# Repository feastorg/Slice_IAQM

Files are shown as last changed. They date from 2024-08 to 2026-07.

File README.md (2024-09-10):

# Industrial Air Quality Monitor

Industrial air quality monitor and alarm for BREAD.

## Introduction

[Short introduction on the project.]

## Usage

[Explain how to use the project. Include examples and screenshots if applicable.]

## Documentation

Please refer to the [docs](/docs) for more info.

---

<div align="center">
  <p>
    
    
  </p>
</div>

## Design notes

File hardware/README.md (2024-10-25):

## IAQM - Industrial Air Quality Monitor 

## Requirements

### Requirements List

- **Data Logging**
  - Logging of data to SD card
  - Real-time clock for accurate data logging

- **Feedback Alarms**
  - Visual feedback alarm
  - Auditory feedback alarm

- **Air Quality Readings**
  - Ambient temperature sensor
  - Ambient humidity sensor
  - Barometric pressure sensor
  - CO gas sensor
  - CH₄ gas sensor
  - NH₃ gas sensor
  - H₂S gas sensor
  - H₂ gas sensor
  - Smoke / flammable gas sensor
  - VOCs (Volatile Organic Compounds)
    - eCO2 readings
  - AQI (Air Quality Index)

### Component Table

| **Name** | **Parameters Measured** | **Value Abbreviation** | **Notes** |
|---|---|---|---|
| SD Card Reader | Data Logging | N/A | |
| Real Time Clock | Global Local Time | N/A | |
| Piezo Buzzer | Auditory Feedback | N/A | For Alarm |
| Large LED | Visual Feedback | N/A | For Alarm |
| MQ-7 | Carbon Monoxide | CO | 10～500ppm, needs cycled coil heating. |
| MQ-137 | Ammonia Gas | NH₃ | 5～500ppm |
| MQ-8 | Hydrogen Gas | H₂ | 100～1000ppm |
| MQ-136 | Hydrogen Sulfide Gas | H₂S | 1～200ppm |
| MQ-2 | Smoke / Combustible Gas | N/A | 300～10000ppm (flammable gas) |
| MQ-3 | Alcohol Gas | C₂H₅OH | 25 ~ 500ppm (alcohol). Detects alcohol gases like a breathalyzer, not added in default build. |
| MQ-4 | Methane CNG Gas | CH₄ | 300～10000ppm |
| MQ-6 | Liquefied Petroleum Gas (LPG) | C₃H₈ | 300～10000ppm (propane). Not in default build. |
| BME 280 | Ambient Temperature, Relative Humidity, Barometric Pressure | N/A | Ambient Temp. -40 - +85 °C, Rel. Humidity 0 - 100 %, Baro. Pressure 300 - 1100 hPa |
| ENS160 | Total Volatile Organic Compounds, Equivalent Carbon Dioxide, Air Quality Index | TVOC, eCO₂, AQI | TVOC 0 – 65,000 ppb, eCO2 400 – 65,000ppm (CO₂ equiv.), AQI-UBA 1 to 5 |

### PV Box

| **Name** | **Parameters Measured** | **Value Abbreviation** | **Notes** |
|---|---|---|---|
| SD Card Reader | Data Logging | N/A | |
| Real Time Clock | Global Local Time | N/A | |
| Piezo Buzzer | Auditory Feedback | N/A | For Alarm |
| Large LED | Visual Feedback | N/A | For Alarm |
| MQ-7 | Carbon Monoxide | CO | 10～500ppm, needs cycled coil heating. |
| MQ-137 | Ammonia Gas | NH₃ | 5～500ppm |
| MQ-8 | Hydrogen Gas | H₂ | 100～1000ppm |
| MQ-136 | Hydrogen Sulfide Gas | H₂S | 1～200ppm |
| MQ-4 | Methane CNG Gas | CH₄ | 300～10000ppm |
| MQ-9B | Carbon Monoxide & Methane CNG Gas | CO & CH₄ | 10～500ppm CO, 300～10000ppm CH4 |
| BME 280 | Ambient Temperature, Relative Humidity, Barometric Pressure | N/A | Ambient Temp. -40 - +85 °C, Rel. Humidity 0 - 100 %, Baro. Pressure 300 - 1100 hPa |
| ENS160 | Total Volatile Organic Compounds, Equivalent Carbon Dioxide, Air Quality Index | TVOC, eCO₂, AQI | TVOC 0 – 65,000 ppb, eCO2 400 – 65,000ppm (CO₂ equiv.), AQI-UBA 1 to 5 |

### Parts List

- SD conn: https://www.mouser.ca/ProductDetail/Molex/502570-0893?qs=xbccQsLEe0eiL%252BVgS3E4nA%3D%3D
- SD level shifter: https://www.mouser.ca/ProductDetail/Texas-Instruments/TXB0104D?qs=oFXvjAmG9Eh0u9dpGkn5zg%3D%3D
- batt holder: https://www.mouser.ca/ProductDetail/Keystone-Electronics/3000?qs=Mn60vILZNNbcLh3ZnzbtUw%3D%3D

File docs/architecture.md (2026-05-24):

---
title: "Architecture"
description: "Hardware and firmware architecture overview."
---

# Architecture

## Hardware

Indoor Air Quality Monitor (IAQM) slice. Integrates BME280 (temp/humidity/pressure), ENS160 (VOC/eCO2), MQ gas sensor, RTC, and microSD card logging with 1.8V regulator.

## Firmware

_Not yet developed._

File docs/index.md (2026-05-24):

---
title: "Slice IAQM Documentation"
description: "Overview and entry page for Slice IAQM project documentation."
nav_exclude: true
---

Welcome to the Slice IAQM project documentation.

## Board Renders

<figure style="display:inline-block; text-align:center; margin:10px;">
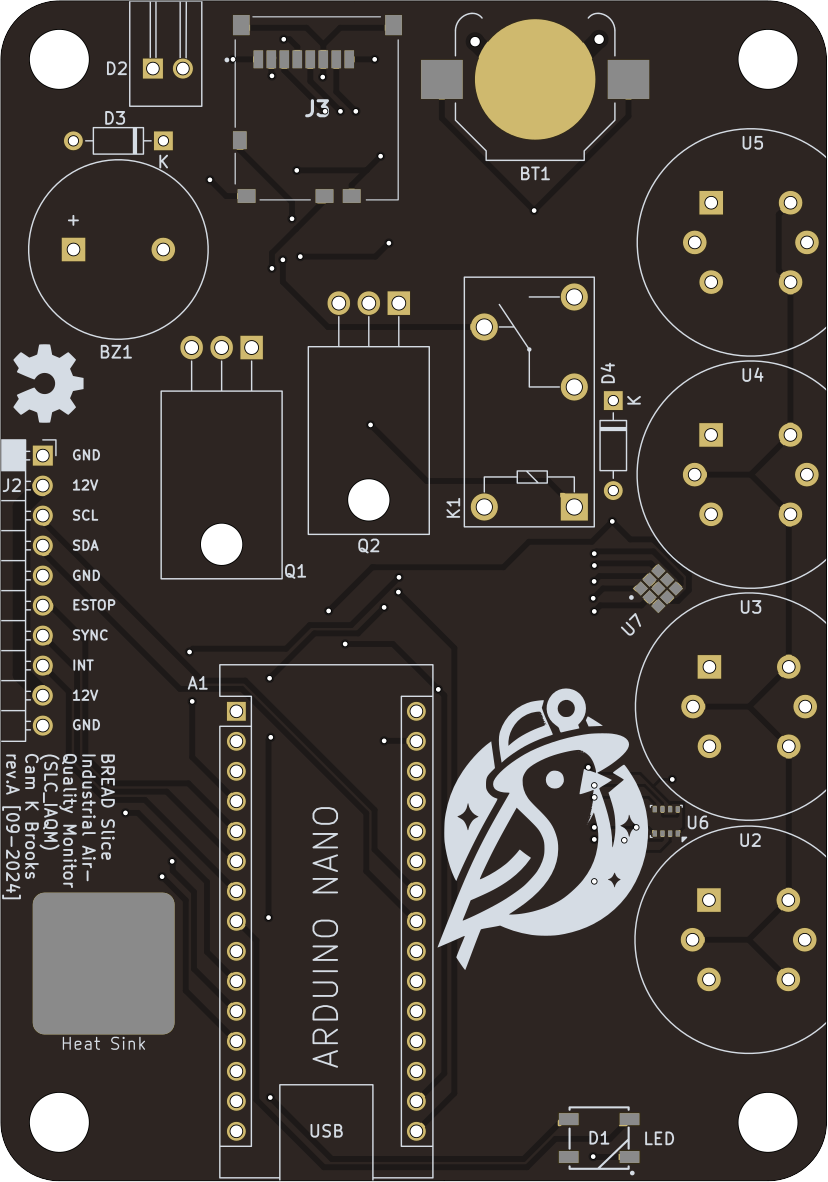
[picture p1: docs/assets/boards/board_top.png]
Board Top
  
  <figcaption>Top</figcaption>
</figure>

<figure style="display:inline-block; text-align:center; margin:10px;">
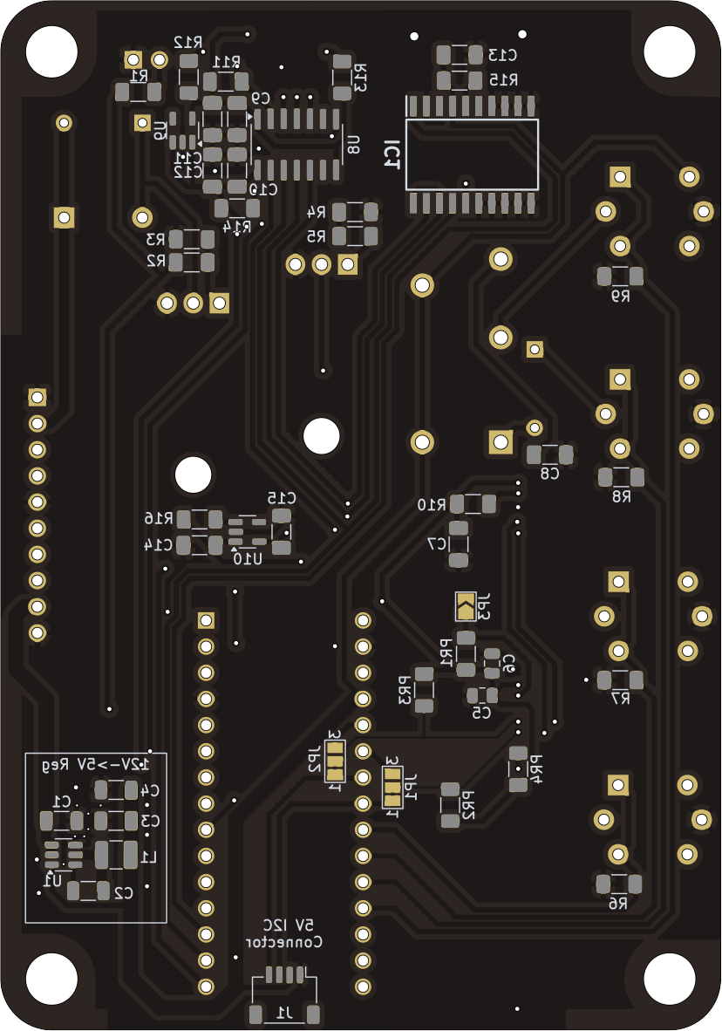
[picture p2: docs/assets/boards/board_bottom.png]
Board Bottom
  
  <figcaption>Bottom</figcaption>
</figure>

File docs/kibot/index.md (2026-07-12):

---
title: "KiBot Outputs"
description: "Index for KiBot-generated PCB artifacts."
layout: "page"
---

These are the docs & KiBot Outputs for Slice IAQM

The following files were generated from the latest PCB build:

- [Schematic.pdf](./Schematic.pdf)
- [PCB.pdf](./PCB.pdf)
- [kibot.log](./kibot.log)
- [BREAD_Slice-bom.html](./BREAD_Slice-bom.html)
- [BREAD_Slice-ibom.html](./BREAD_Slice-ibom.html)

_Last updated automatically on 2026-07-12 at 03:58:19 UTC by KiBot via GitHub Actions._

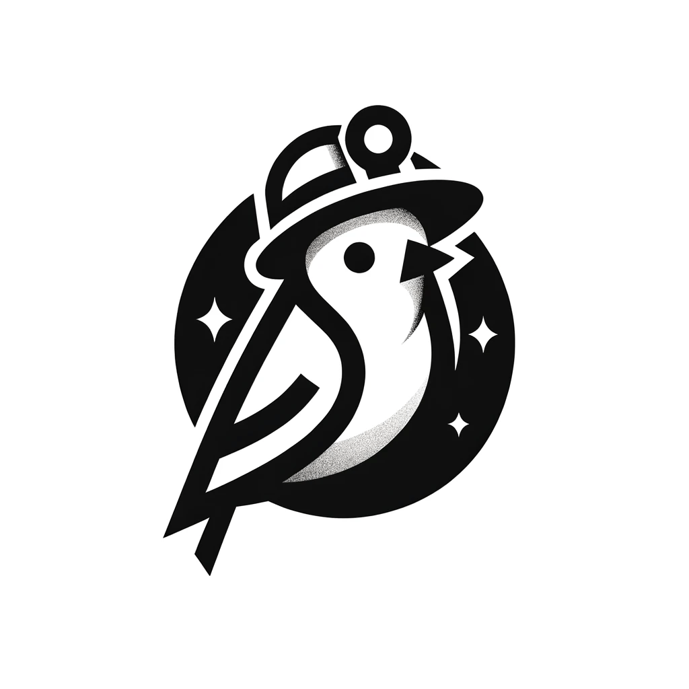
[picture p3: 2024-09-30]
hardware/canary_coal_miner.png

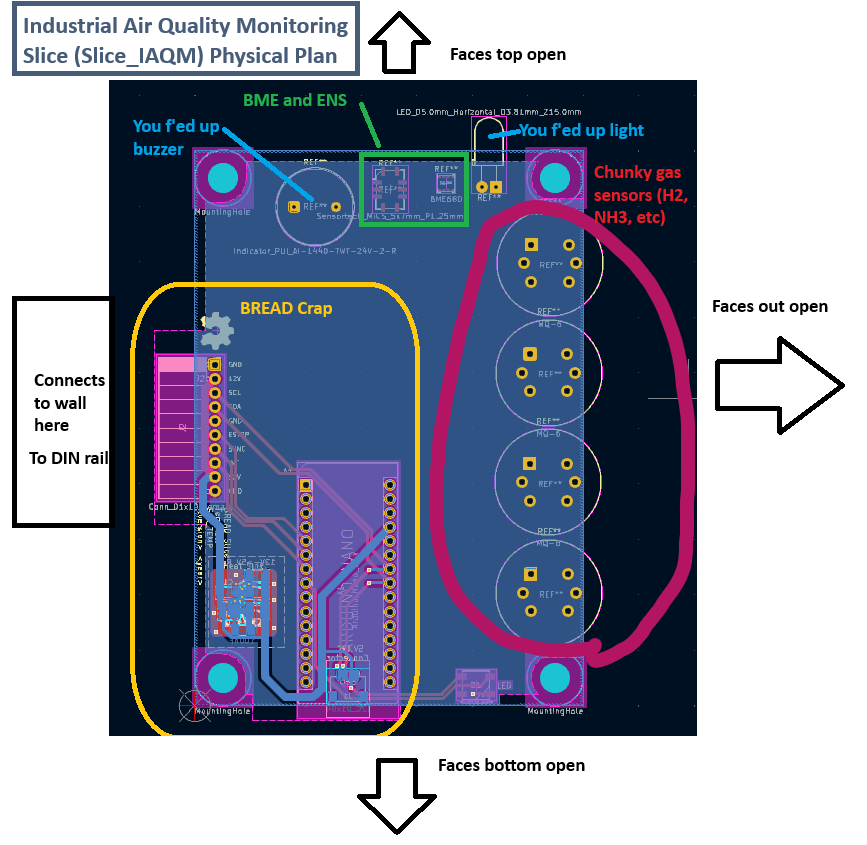
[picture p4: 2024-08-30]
docs/physical_layout_planning.png

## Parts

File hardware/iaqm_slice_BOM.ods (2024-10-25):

Reference | Value | Purchase Link | Datasheet | Footprint | Qty | Cost / Unit | Cost
A1 | Arduino_Nano_v3.x | https://www.mouser.ca/ProductDetail/Arduino/ABX00033 | http://www.mouser.com/pdfdocs/Gravitech_Arduino_Nano3_0.pdf | Module:Arduino_Nano | 1 | $21.32 | $21.32
BT1 | Battery_Cell | https://www.mouser.ca/ProductDetail/Keystone-Electronics/3000?qs=Mn60vILZNNbcLh3ZnzbtUw%3D%3D | https://www.mouser.ca/ProductDetail/Keystone-Electronics/3000?qs=Mn60vILZNNbcLh3ZnzbtUw%3D%3D | Battery:BatteryHolder_Keystone_3000_1x12mm | 1 | $0.53 | $0.53
BZ1 | CX-1612C | https://www.mouser.ca/ProductDetail/Same-Sky/CX-1612C?qs=WyjlAZoYn51Lu2CSChkNrQ%3D%3D | ~ | Buzzer_Beeper:Buzzer_15x7.5RM7.6 | 1 | $2.86 | $2.86
C1,C3,C4 | 22u | https://www.digikey.ca/en/products/detail/samsung-electro-mechanics/CL31A226KAHNNNE/3888705 | ~ | Capacitor_SMD:C_1206_3216Metric | 3 | $0.57 | $1.71
C2, C7,C9,C10 | 0.1u | https://www.digikey.ca/en/products/detail/samsung-electro-mechanics/CL31B104KBCNNNC/3886675 | ~ | Capacitor_SMD:C_1206_3216Metric | 4 | $0.16 | $0.64
C5,C6 | 0.1u | https://www.digikey.ca/en/products/detail/kemet/C0805C104K5RAC7800/411169 | ~ | Capacitor_SMD:C_0805_2012Metric | 2 | $0.20 | $0.40
C8 | 10u | https://www.digikey.ca/en/products/detail/kemet/C1206C106K3PAC7800/2215114 | ~ | Capacitor_SMD:C_1206_3216Metric_Pad1.33x1.80mm_HandSolder | 1 | $0.54 | $0.54
C11,C12 | 1.0u | https://www.digikey.ca/en/products/detail/kemet/C1206C104KARAC7800/992167 | ~ | Capacitor_SMD:C_1206_3216Metric_Pad1.33x1.80mm_HandSolder | 2 | $0.52 | $1.04
C13 | 22p | https://www.digikey.ca/en/products/detail/kemet/C1206C220JGGAC7800/2215422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 | ~ | Capacitor_SMD:C_1206_3216Metric_Pad1.33x1.80mm_HandSolder | 1 | $1.06 | $1.06
C14,C15 | 1u | https://www.digikey.ca/en/products/detail/walsin-technology-corporation/1206B103J500CT/9355096 | ~ | Capacitor_SMD:C_1206_3216Metric_Pad1.33x1.80mm_HandSolder | 2 | $0.28 | $0.56
D1 | WS2812B_5050 | https://www.digikey.ca/en/products/detail/sparkfun-electronics/COM-16347/11630204 | https://cdn.sparkfun.com/datasheets/BreakoutBoards/WS2812B.pdf | SparkFun-LED:WS2812-5050-4PIN | 1 | $0.93 | $0.93
D2 | H178CAD | https://www.mouser.ca/ProductDetail/Bivar/H178CAD?qs=LbIio39SXC0jTCktxHQegA%3D%3D | ~ | KML-Custom:H178CAD_P2.54mm_RightAngle_LED | 1 | $1.09 | $1.09
D3 | 1N4007 | https://www.mouser.ca/ProductDetail/Diotec-Semiconductor/1N4007?qs=OlC7AqGiEDmK9mU1uTiCkg%3D%3D | https://assets.nexperia.com/documents/data-sheet/1N4148_1N4448.pdf | Diode_THT:D_DO-35_SOD27_P7.62mm_Horizontal | 1 | $0.15 | $0.15
D4 | 1N4148 | https://www.mouser.ca/ProductDetail/onsemi-Fairchild/1N4148?qs=i4Fj9T%2FoRm8RMUhj5DeFQg%3D%3D | https://assets.nexperia.com/documents/data-sheet/1N4148_1N4448.pdf | Diode_THT:D_DO-35_SOD27_P7.62mm_Horizontal | 1 | $0.15 | $0.15
H1,H2,H3,H4 | MountingHole | N/A | ~ | MountingHole:MountingHole_5mm | 4 | $0.00 | $0.00
HS1 | Heatsink_Pad | N/A | ~ | KML-Custom:Thermal Pad | 1 | $0.00 | $0.00
IC1 | DS3234S# | https://www.mouser.ca/ProductDetail/Analog-Devices-Maxim-Integrated/DS3234S?qs=1eQvB6Dk1vhNRvcRKqeJUg%3D%3D | https://datasheets.maximintegrated.com/en/ds/DS3234.pdf | KML-Custom:SOIC127P1032X265-20N | 1 | $16.72 | $16.72
J1 | I2C_01x04 | https://www.digikey.ca/en/products/detail/jst-sales-america-inc/SM04B-SRSS-TB/926710 | ~ | Connector_JST:JST_SH_SM04B-SRSS-TB_1x04-1MP_P1.00mm_Horizontal | 1 | $1.03 | $1.03
J2 | Conn_01x10_Female | https://www.digikey.ca/en/products/detail/sullins-connector-solutions/PPTC101LGBN-RC/775904 | ~ | Connector_PinSocket_2.54mm:PinSocket_1x10_P2.54mm_Horizontal | 1 | $1.37 | $1.37
J3 | MicroSD_502570-0893 | https://www.mouser.ca/ProductDetail/Molex/502570-0893?qs=xbccQsLEe0eiL%252BVgS3E4nA%3D%3D | https://componentsearchengine.com/Datasheets/2/502570-0893.pdf | KML-Custom:MicroSD_5025700893 | 1 | $6.29 | $6.29
JP3 | Jumper_2_Open | N/A | ~ | Jumper:SolderJumper-2_P1.3mm_Open_TrianglePad1.0x1.5mm | 1 | $0.00 | $0.00
K2 | G5Q-1 | https://www.digikey.ca/en/products/detail/omron-electronics-inc-emc-div/G5Q-1-DC5/1815726 | https://www.omron.com/ecb/products/pdf/en-g5q.pdf | Relay_THT:Relay_SPDT_Omron-G5Q-1 | 1 | $2.32 | $2.32
L1 | 4.7uH | https://www.digikey.ca/en/products/detail/tdk-corporation/BCL322520RT-4R7M-D/15849704 | ~ | Inductor_SMD:L_1210_3225Metric | 1 | $2.32 | $2.32
Q1,Q2 | IRLZ34N | https://www.digikey.ca/en/products/detail/infineon-technologies/IRLZ34NPBF/811725 | http://www.infineon.com/dgdl/irlz34npbf.pdf?fileId=5546d462533600a40153567206892720 | Package_TO_SOT_THT:TO-220-3_Horizontal_TabDown | 2 | $2.15 | $4.30
PR1,PR2,PR3,PR4,R6,R7,R8,R9 | 4.7k | https://www.digikey.ca/en/products/detail/yageo/RC1206FR-074K7L/728887 | ~ | Resistor_SMD:R_1206_3216Metric_Pad1.30x1.75mm_HandSolder | 8 | $0.15 | $1.20
R1 | 85 | https://www.digikey.ca/en/products/detail/stackpole-electronics-inc/RMCF1206FT84R5/1754203 | ~ | Resistor_SMD:R_1206_3216Metric_Pad1.30x1.75mm_HandSolder | 1 | $0.15 | $0.15
R2,R5 | 220 | https://www.digikey.ca/en/products/detail/stackpole-electronics-inc/RMCF1206FT220R/1759830 | ~ | Resistor_SMD:R_1206_3216Metric_Pad1.30x1.75mm_HandSolder | 2 | $0.15 | $0.30
R3,R4,R10,R15,R16 | 10k | https://www.digikey.ca/en/products/detail/stackpole-electronics-inc/RMCF1206FT10K0/1759669 | ~ | Resistor_SMD:R_1206_3216Metric_Pad1.30x1.75mm_HandSolder | 5 | $0.15 | $0.75
R11,R12,R13,R14 | 100k | https://www.digikey.ca/en/products/detail/stackpole-electronics-inc/RMCF1206FT100K/1759689 | ~ | Resistor_SMD:R_1206_3216Metric_Pad1.30x1.75mm_HandSolder | 4 | $0.15 | $0.60
U1 | AP63205WU-7 | https://www.mouser.ca/ProductDetail/Diodes-Incorporated/AP63205WU-7?qs=u16ybLDytRZtkj8PzdWCOw%3D%3D |  | Package_TO_SOT_SMD:TSOT-23-6 | 1 | $1.26 | $1.26
U2,U3,U4,U5 | MQ-7 | https://www.sparkfun.com/products/9403 | https://www.winsen-sensor.com/d/files/semiconductor/mq-6.pdf | Sensor:MQ-6 | 1 | $5.50 | $5.50
U2,U3,U4,U5 | MQ-137 | https://www.sparkfun.com/products/17053 | https://www.winsen-sensor.com/d/files/semiconductor/mq-6.pdf | Sensor:MQ-7 | 1 | $37.50 | $37.50
U2,U3,U4,U5 | MQ-8 | https://www.sparkfun.com/products/10916 | https://www.winsen-sensor.com/d/files/semiconductor/mq-6.pdf | Sensor:MQ-8 | 1 | $5.50 | $5.50
U2,U3,U4,U5 | MQ-136 | https://www.sparkfun.com/products/17052 | https://www.winsen-sensor.com/d/files/semiconductor/mq-6.pdf | Sensor:MQ-9 | 1 | $37.50 | $37.50
U2,U3,U4,U5 | MQ-4 | https://www.sparkfun.com/products/9404 | https://www.winsen-sensor.com/d/files/semiconductor/mq-6.pdf | Sensor:MQ-10 | 1 | $5.50 | $5.50
U2,U3,U4,U5 | MQ-9B | https://www.sparkfun.com/products/17050 | https://www.winsen-sensor.com/d/files/semiconductor/mq-6.pdf | Sensor:MQ-6 | 1 | $6.50 | $6.50
U6 | BME280 | https://www.mouser.ca/ProductDetail/Bosch-Sensortec/BME280?qs=2OnyuXx6vpj2fK9HX7qb3g%3D%3D | https://www.bosch-sensortec.com/media/boschsensortec/downloads/datasheets/bst-bme280-ds002.pdf | Package_LGA:Bosch_LGA-8_2.5x2.5mm_P0.65mm_ClockwisePinNumbering | 1 | $8.74 | $8.74
U7 | ENS160-BGLM | https://www.mouser.ca/ProductDetail/ScioSense/ENS160-BGLM?qs=DRkmTr78QAQKsjT0z3MHoA%3D%3D |  | KML-Custom:XDCR_ENS160-BGLM | 1 | $13.11 | $13.11
U8 | TXB0104D | https://www.mouser.ca/ProductDetail/Texas-Instruments/TXB0104D?qs=oFXvjAmG9Eh0u9dpGkn5zg%3D%3D | http://www.ti.com/lit/ds/symlink/txb0104.pdf | Package_SO:SOIC-14_3.9x8.7mm_P1.27mm | 1 | $2.02 | $2.02
U9 | AP2112K-3.3 | https://www.mouser.ca/ProductDetail/Diodes-Incorporated/AP2112K-3.3TRG1?qs=x6A8l6qLYDDPYHosCdzh%2FA%3D%3D | https://www.diodes.com/assets/Datasheets/AP2112.pdf | Package_TO_SOT_SMD:SOT-23-5 | 1 | $0.32 | $0.32
U10 | AP2127K-1.8 | https://www.mouser.ca/ProductDetail/Diodes-Incorporated/AP2127K-1.8TRG1?qs=x6A8l6qLYDDmU4WXw4%252BBlA%3D%3D | https://www.diodes.com/assets/Datasheets/AP2127.pdf | Package_TO_SOT_SMD:SOT-23-5 | 1 | $0.38 | $0.38
 |  |  |  |  |  |  | $194.16

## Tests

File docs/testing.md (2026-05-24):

---
title: "Testing"
description: "Test procedures and results."
---

# Testing

_No tests defined yet. Will be populated during validation phase._

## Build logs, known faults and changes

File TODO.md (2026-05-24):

# Slice_IAQM TODO

## CI Results (Pass 1)

- [x] DRC: PASS
- [x] ERC: PASS
- [x] Fab (gerbers, BOM, renders): PASS
- [x] gen-kibot-index: PASS
- [x] deploy-pages: PASS

## Pass 2 – Pre-fab Review

- [ ] Verify BOM completeness
- [ ] Confirm board outline and mounting holes
- [ ] Update README.md (still says "Slice Template")

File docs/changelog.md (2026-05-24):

---
title: "Changelog"
description: "Hardware and firmware revision history."
---

# Changelog

## Hardware

### v0.1.0 (initial)
- Initial schematic and PCB layout
- BME280, ENS160, MQ gas sensor, RTC, microSD sub-circuits
- 1.8V regulator for ENS160

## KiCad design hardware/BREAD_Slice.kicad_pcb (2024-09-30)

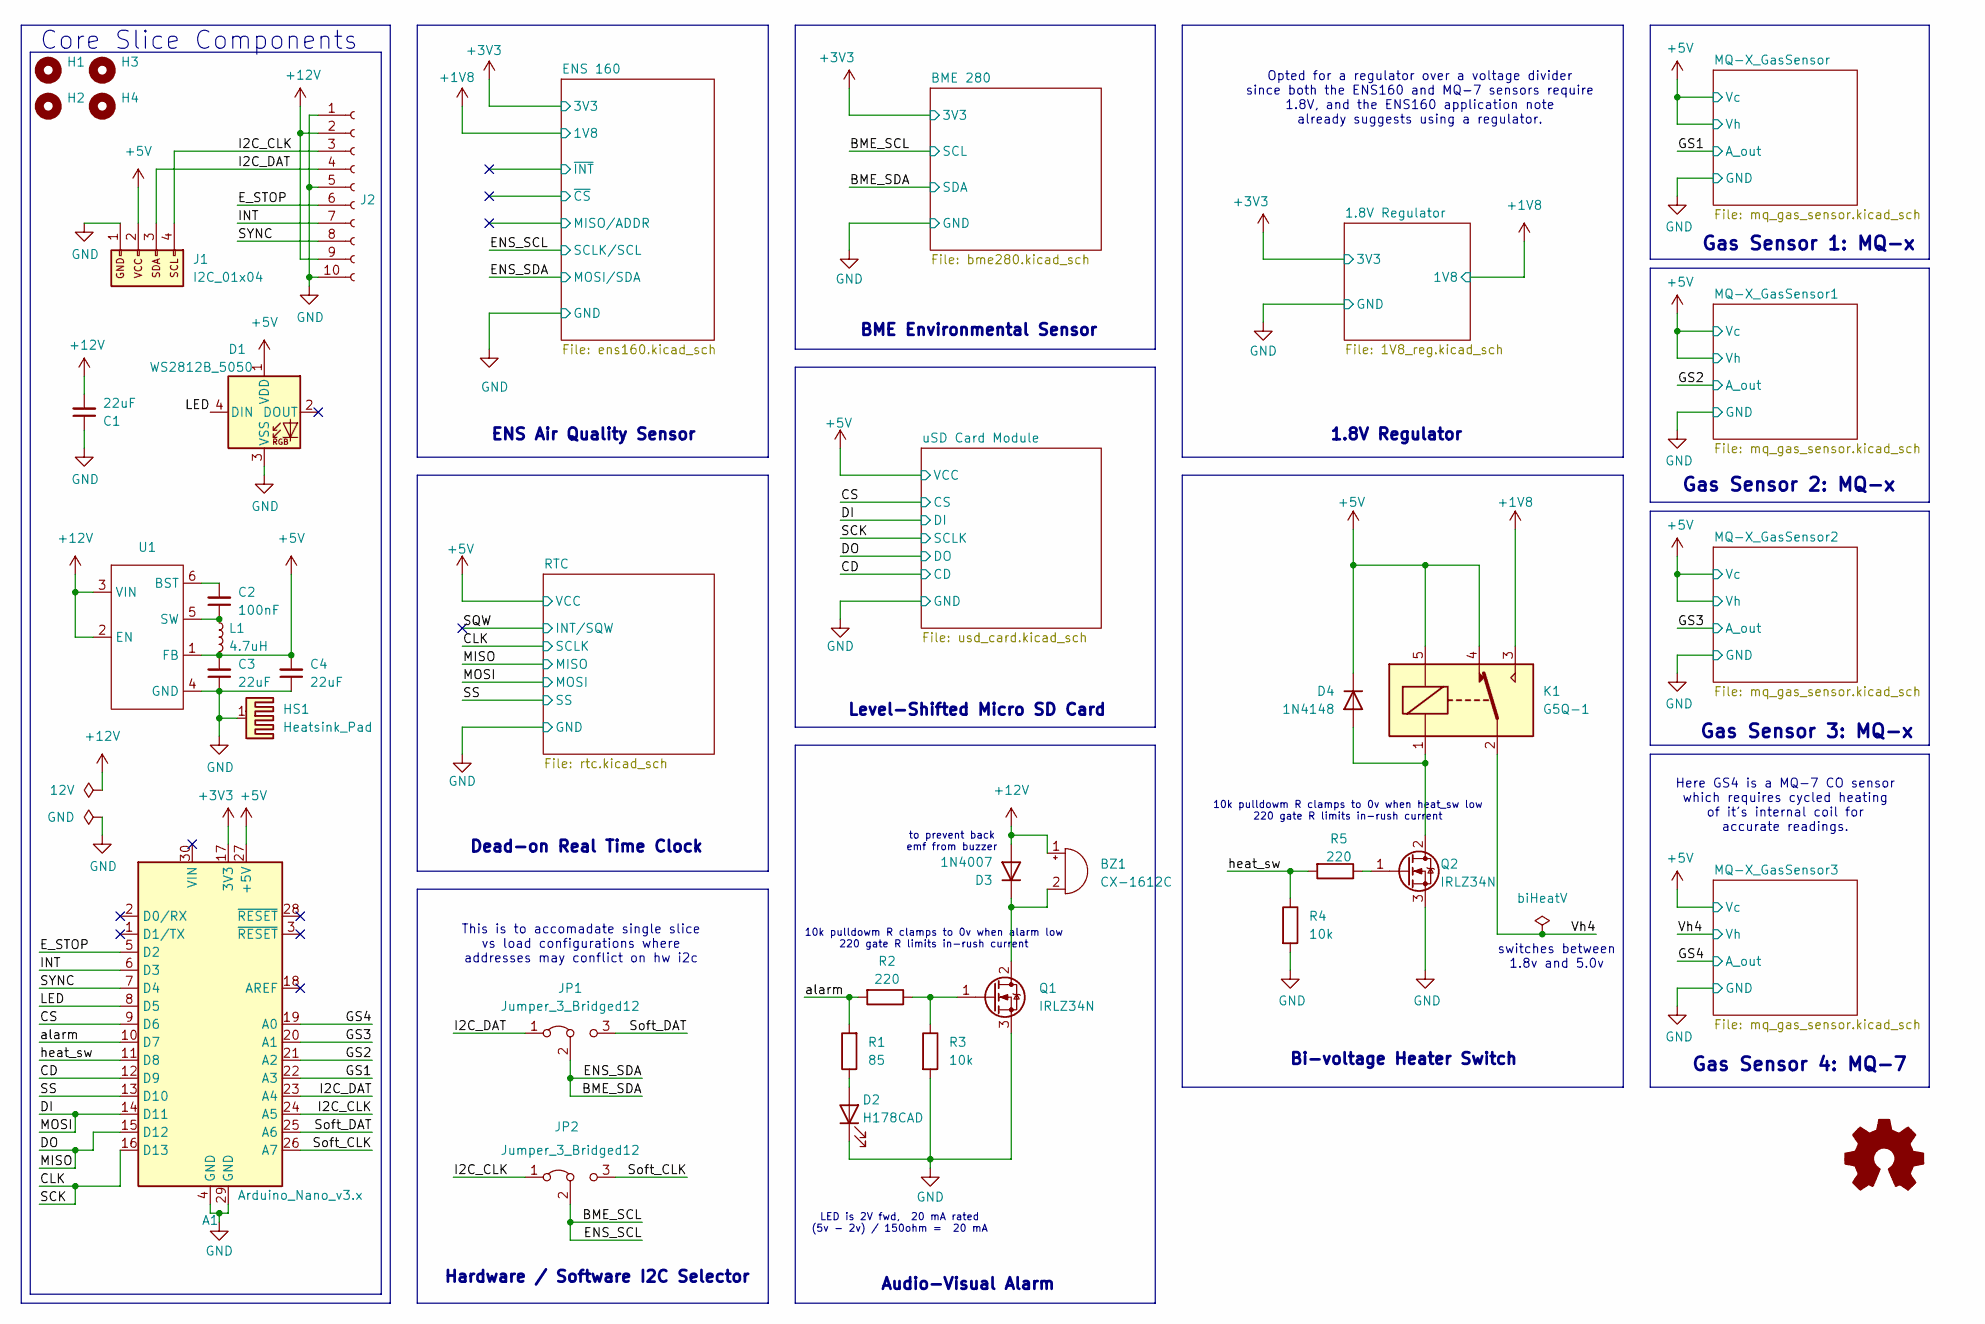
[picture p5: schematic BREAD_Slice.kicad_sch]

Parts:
A1: Arduino_Nano_v3.x; Arduino_Nano
BZ1: CX-1612C; Buzzer_15x7.5RM7.6
C1, C3, C4: 22uF; C_1206_3216Metric
C2: 100nF; C_1206_3216Metric
D1: WS2812B_5050; WS2812-5050-4PIN
D2: H178CAD; H178CAD_P2.54mm_RightAngle_LED
D3: 1N4007; D_DO-35_SOD27_P7.62mm_Horizontal
D4: 1N4148; D_DO-35_SOD27_P7.62mm_Horizontal
H1, H2, H3, H4: MountingHole; MountingHole_5mm
HS1: Heatsink_Pad; Thermal Pad
J1: I2C_01x04; JST_SH_SM04B-SRSS-TB_1x04-1MP_P1.00mm_Horizontal
J2: Conn_01x10_Female; PinSocket_1x10_P2.54mm_Horizontal
JP1, JP2: Jumper_3_Bridged12; SolderJumper-3_P1.3mm_Bridged2Bar12_Pad1.0x1.5mm_NumberLabe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
K1: G5Q-1; Relay_SPDT_Omron-G5Q-1
L1: 4.7uH; L_1210_3225Metric
Q1, Q2: IRLZ34N; TO-220-3_Horizontal_TabDown
R1: 85; R_1206_3216Metric_Pad1.30x1.75mm_HandSolder
R2, R5: 220; R_1206_3216Metric_Pad1.30x1.75mm_HandSolder
R3, R4: 10k; R_1206_3216Metric_Pad1.30x1.75mm_HandSolder
U1: TSOT-23-6

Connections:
+1V8: K1.3; also elsewhere on the board
+3V3: A1.17 (3V3); also elsewhere on the board
+5V: A1.27 (+5V), C3.2, C4.2, D1.1 (VDD), D4.1 (K), J1.2, K1.4, K1.5, L1.2, U1.1 (FB); also elsewhere on the board
+12V: BZ1.1 (+), C1.2, D3.2 (A), J2.2, J2.9, U1.2 (EN), U1.3 (VIN)
/BME_SCL: JP2.2 (C); also elsewhere on the board
/BME_SDA: JP1.2 (C); also elsewhere on the board
/CD: A1.12 (D9); also elsewhere on the board
/CLK: A1.16 (D13); also elsewhere on the board
/CS: A1.9 (D6); also elsewhere on the board
/DI: A1.14 (D11); also elsewhere on the board
/DO: A1.15 (D12); also elsewhere on the board
/E_STOP: A1.5 (D2), J2.6
/GS1: A1.22 (A3); also elsewhere on the board
/GS2: A1.21 (A2); also elsewhere on the board
/GS3: A1.20 (A1); also elsewhere on the board
/GS4: A1.19 (A0); also elsewhere on the board
/I2C_CLK: A1.24 (A5), J1.4, J2.3, JP2.1 (A)
/I2C_DAT: A1.23 (A4), J1.3, J2.4, JP1.1 (A)
/INT: A1.6 (D3), J2.7
/LED: A1.8 (D5), D1.4 (DIN)
/SS: A1.13 (D10); also elsewhere on the board
/SYNC: A1.7 (D4), J2.8
/Soft_CLK: A1.26 (A7), JP2.3 (B)
/Soft_DAT: A1.25 (A6), JP1.3 (B)
/Vh4: K1.2; also elsewhere on the board
/alarm: A1.10 (D7), R1.2, R2.2
/heat_sw: A1.11 (D8), R4.1, R5.2
GND: A1.4 (GND), A1.29 (GND), C1.1, C3.1, C4.1, D1.3 (VSS), D2.1 (K), HS1.1, J1.1, J2.1, J2.5, J2.10, Q1.3 (S), Q2.3 (S), R3.2, R4.2, U1.4 (GND); also elsewhere on the board
unnamed: BZ1.2 (-), D3.1 (K), Q1.2 (D)
unnamed: D2.2 (A), R1.1
unnamed: D4.2 (A), K1.1, Q2.2 (D)
unnamed: Q1.1 (G), R2.1, R3.1
unnamed: Q2.1 (G), R5.1
unnamed: C2.2, U1.6 (BST)
unnamed: C2.1, L1.1, U1.5 (SW)

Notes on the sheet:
Gas Sensor 2: MQ-x
LED is 2V fwd, 20 mA rated (5v - 2v) / 150ohm = 20 mA
Gas Sensor 1: MQ-x
Bi-voltage Heater Switch
Gas Sensor 4: MQ-7
Gas Sensor 3: MQ-x
switches between 1.8v and 5.0v
1.8V Regulator
Level-Shifted Micro SD Card
Audio-Visual Alarm
Core Slice Components
BME Environmental Sensor
10k pulldowm R clamps to 0v when heat_sw low 220 gate R limits in-rush current
to prevent back emf from buzzer
10k pulldowm R clamps to 0v when alarm low 220 gate R limits in-rush current
Opted for a regulator over a voltage divider since both the ENS160 and MQ-7 sensors require 1.8V, and the ENS160 application note already suggests using a regulator.
ENS Air Quality Sensor
Dead-on Real Time Clock
This is to accomadate single slice vs load configurations where addresses may conflict on hw i2c
Here GS4 is a MQ-7 CO sensor which requires cycled heating of it's internal coil for accurate readings.
Hardware / Software I2C Selector

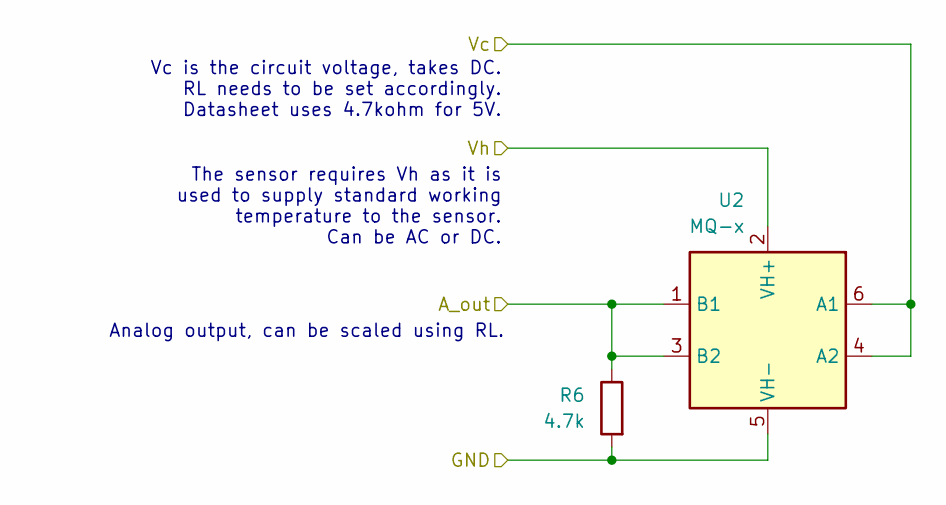
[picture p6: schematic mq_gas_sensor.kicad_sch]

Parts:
R6: 4.7k; R_1206_3216Metric_Pad1.30x1.75mm_HandSolder
U2: MQ-x; MQ-6

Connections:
+5V: U2.2 (VH+), U2.4 (A2), U2.6 (A1); also elsewhere on the board
/GS1: R6.1, U2.1 (B1), U2.3 (B2); also elsewhere on the board
GND: R6.2, U2.5 (VH-); also elsewhere on the board

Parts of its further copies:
R7, R8, R9: 4.7k; R_1206_3216Metric_Pad1.30x1.75mm_HandSolder
U3, U4, U5: MQ-x; MQ-6

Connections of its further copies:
+5V: U3.2 (VH+), U3.4 (A2), U3.6 (A1), U4.2 (VH+), U4.4 (A2), U4.6 (A1), U5.4 (A2), U5.6 (A1); also elsewhere on the board
/GS2: R7.1, U3.1 (B1), U3.3 (B2); also elsewhere on the board
/GS3: R8.1, U4.1 (B1), U4.3 (B2); also elsewhere on the board
/GS4: R9.1, U5.1 (B1), U5.3 (B2); also elsewhere on the board
/Vh4: U5.2 (VH+); also elsewhere on the board
GND: R7.2, R8.2, R9.2, U3.5 (VH-), U4.5 (VH-), U5.5 (VH-); also elsewhere on the board

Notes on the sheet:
The sensor requires Vh as it is used to supply standard working temperature to the sensor. Can be AC or DC.
Analog output, can be scaled using RL.
Vc is the circuit voltage, takes DC. RL needs to be set accordingly. Datasheet uses 4.7kohm for 5V.

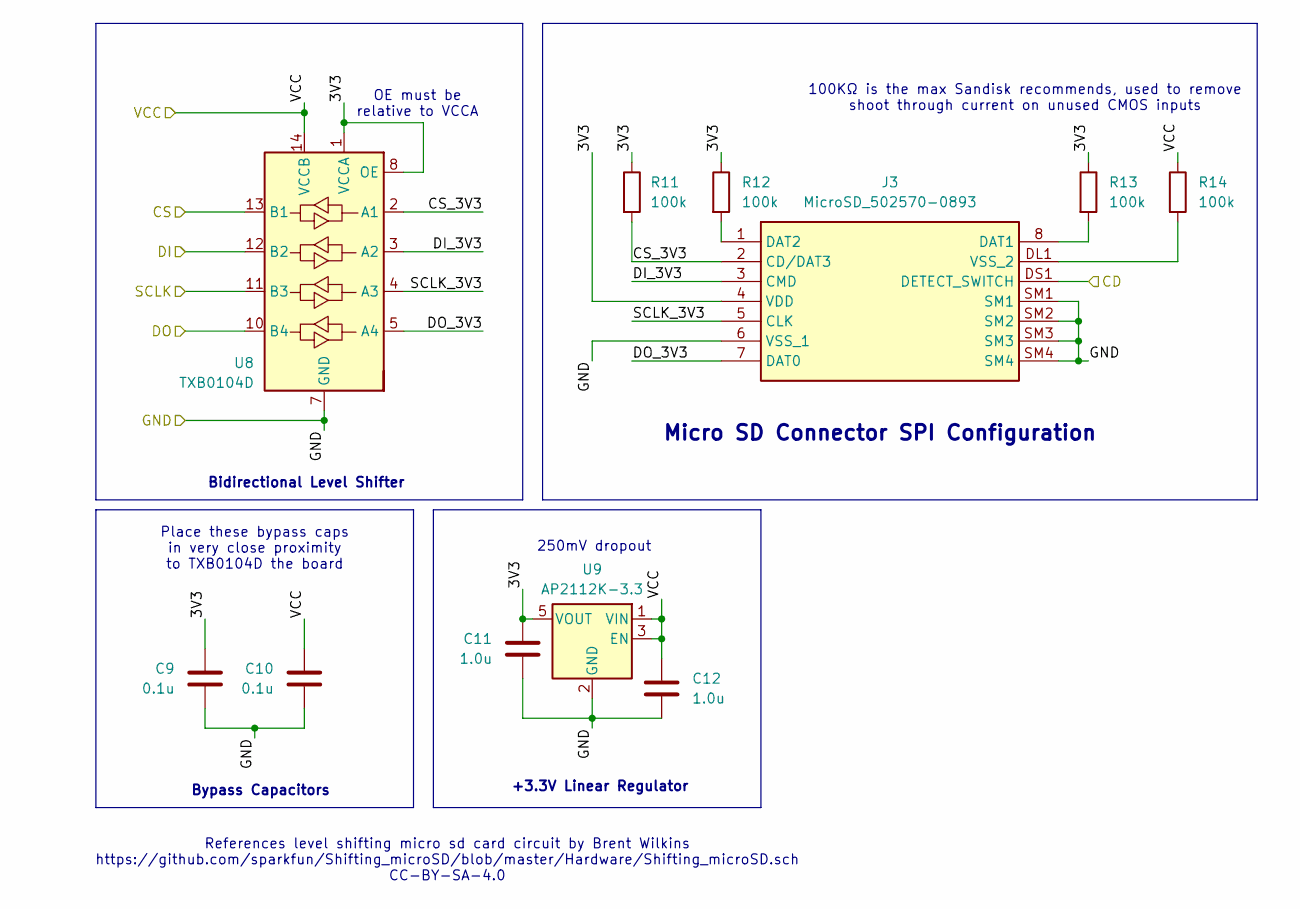
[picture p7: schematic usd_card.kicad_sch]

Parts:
C9, C10: 0.1u; C_1206_3216Metric_Pad1.33x1.80mm_HandSolder
C11, C12: 1.0u; C_1206_3216Metric_Pad1.33x1.80mm_HandSolder
J3: MicroSD_502570-0893; MicroSD_5025700893; Mouser Part Number 538-502570-0893
R11, R12, R13, R14: 100k; R_1206_3216Metric_Pad1.30x1.75mm_HandSolder
U8: TXB0104D; SOIC-14_3.9x8.7mm_P1.27mm
U9: AP2112K-3.3; SOT-23-5

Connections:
+5V: C10.1, C12.1, R14.1, U8.14 (VCCB), U9.1 (VIN), U9.3 (EN); also elsewhere on the board
/CD: J3.DS1 (DETECT_SWITCH); also elsewhere on the board
/CLK: U8.11 (B3); also elsewhere on the board
/CS: U8.13 (B1); also elsewhere on the board
/DI: U8.12 (B2); also elsewhere on the board
/DO: U8.10 (B4); also elsewhere on the board
/uSD Card Module/3V3: C9.1, C11.1, J3.4 (VDD), R11.1, R12.1, R13.1, U8.1 (VCCA), U8.8 (OE), U9.5 (VOUT)
/uSD Card Module/CS_3V3: J3.2 (CD/DAT3), R11.2, U8.2 (A1)
/uSD Card Module/DI_3V3: J3.3 (CMD), U8.3 (A2)
/uSD Card Module/DO_3V3: J3.7 (DAT0), U8.5 (A4)
/uSD Card Module/SCLK_3V3: J3.5 (CLK), U8.4 (A3)
GND: C9.2, C10.2, C11.2, C12.2, J3.6 (VSS_1), J3.SM1, J3.SM2, J3.SM3, J3.SM4, U8.7 (GND), U9.2 (GND); also elsewhere on the board
unnamed: J3.8 (DAT1), R13.2
unnamed: J3.1 (DAT2), R12.2
unnamed: J3.DL1 (VSS_2), R14.2

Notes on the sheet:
Bidirectional Level Shifter
Place these bypass caps in very close proximity to TXB0104D the board
+3.3V Linear Regulator
Micro SD Connector SPI Configuration
OE must be relative to VCCA
Bypass Capacitors
References level shifting micro sd card circuit by Brent Wilkins https://github.com/sparkfun/Shifting_microSD/blob/master/Hardware/Shifting_microSD.sch CC-BY-SA-4.0
100KΩ is the max Sandisk recommends, used to remove shoot through current on unused CMOS inputs
250mV dropout

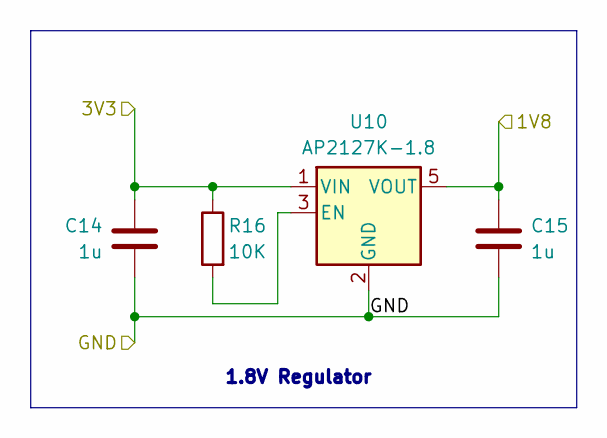
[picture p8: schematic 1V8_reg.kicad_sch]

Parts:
C14, C15: 1u; C_1206_3216Metric_Pad1.33x1.80mm_HandSolder
R16: 10K; R_1206_3216Metric_Pad1.30x1.75mm_HandSolder
U10: AP2127K-1.8; SOT-23-5

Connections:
+1V8: C15.1, U10.5 (VOUT); also elsewhere on the board
+3V3: C14.1, R16.1, U10.1 (VIN); also elsewhere on the board
GND: C14.2, C15.2, U10.2 (GND); also elsewhere on the board
unnamed: R16.2, U10.3 (EN)

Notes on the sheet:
1.8V Regulator

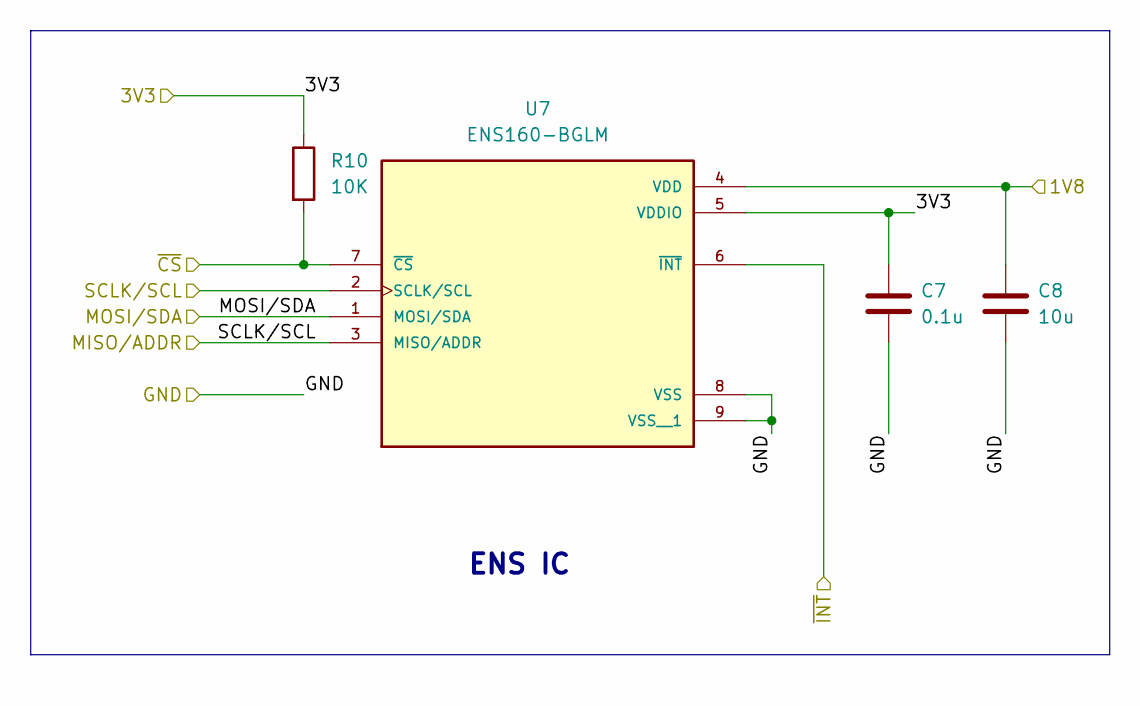
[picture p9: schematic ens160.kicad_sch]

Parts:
C7: 0.1u; C_1206_3216Metric_Pad1.33x1.80mm_HandSolder
C8: 10u; C_1206_3216Metric_Pad1.33x1.80mm_HandSolder
R10: 10K; R_1206_3216Metric_Pad1.30x1.75mm_HandSolder
U7: ENS160-BGLM; XDCR_ENS160-BGLM; PARTREV 1.3

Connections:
+1V8: C8.1, U7.4 (VDD); also elsewhere on the board
+3V3: C7.1, R10.1, U7.5 (VDDIO); also elsewhere on the board
/BME_SCL: U7.2 (SCLK/SCL), U7.3 (MISO/ADDR); also elsewhere on the board
/BME_SDA: U7.1 (MOSI/SDA); also elsewhere on the board
/ENS 160/~CS: R10.2, U7.7 (~CS)
/ENS 160/~INT: U7.6 (~INT)
GND: C7.2, C8.2, U7.8 (VSS), U7.9 (VSS__1); also elsewhere on the board

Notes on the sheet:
ENS IC

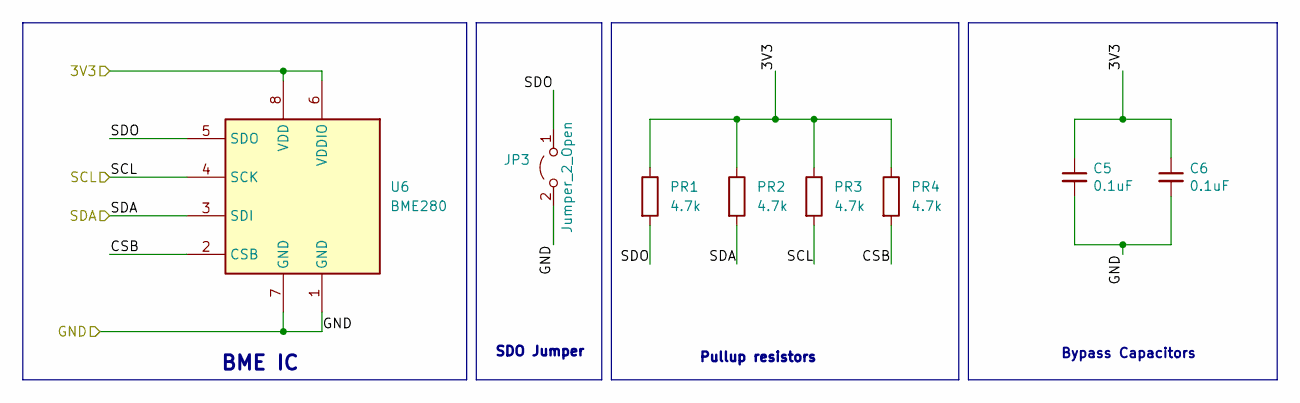
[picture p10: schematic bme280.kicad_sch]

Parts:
C5, C6: 0.1uF; C_0805_2012Metric
JP3: Jumper_2_Open; SolderJumper-2_P1.3mm_Open_TrianglePad1.0x1.5mm
PR1, PR2, PR3, PR4: 4.7k; R_1206_3216Metric_Pad1.30x1.75mm_HandSolder
U6: BME280; Bosch_LGA-8_2.5x2.5mm_P0.65mm_ClockwisePinNumbering

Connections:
+3V3: C5.1, C6.1, PR1.1, PR2.1, PR3.1, PR4.1, U6.6 (VDDIO), U6.8 (VDD); also elsewhere on the board
/BME 280/CSB: PR4.2, U6.2 (CSB)
/BME 280/SDO: JP3.1 (A), PR1.2, U6.5 (SDO)
/BME_SCL: PR3.2, U6.4 (SCK); also elsewhere on the board
/BME_SDA: PR2.2, U6.3 (SDI); also elsewhere on the board
GND: C5.2, C6.2, JP3.2 (B), U6.1 (GND), U6.7 (GND); also elsewhere on the board

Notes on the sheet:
Bypass Capacitors
SDO Jumper
BME IC
Pullup resistors

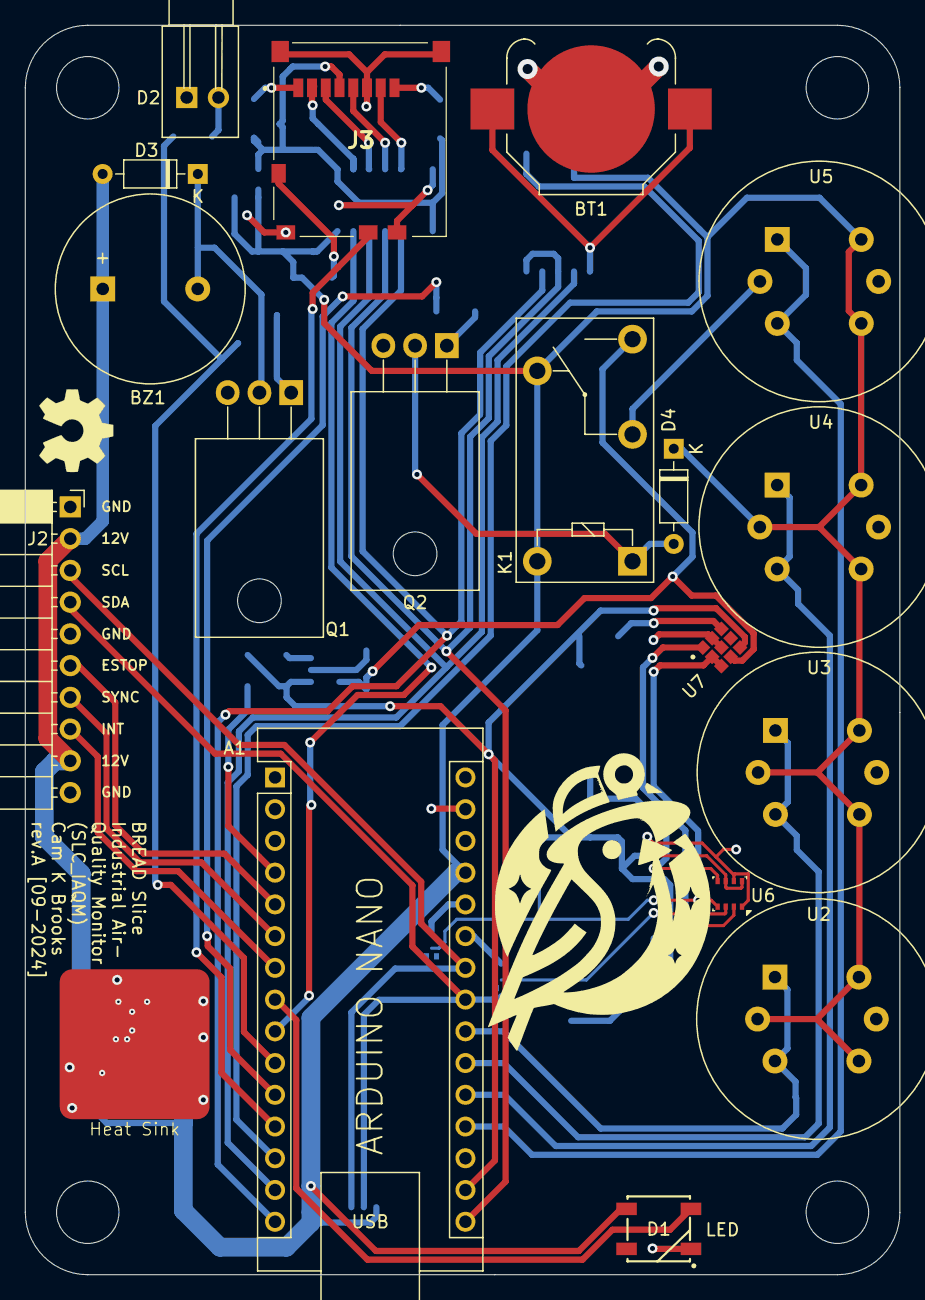
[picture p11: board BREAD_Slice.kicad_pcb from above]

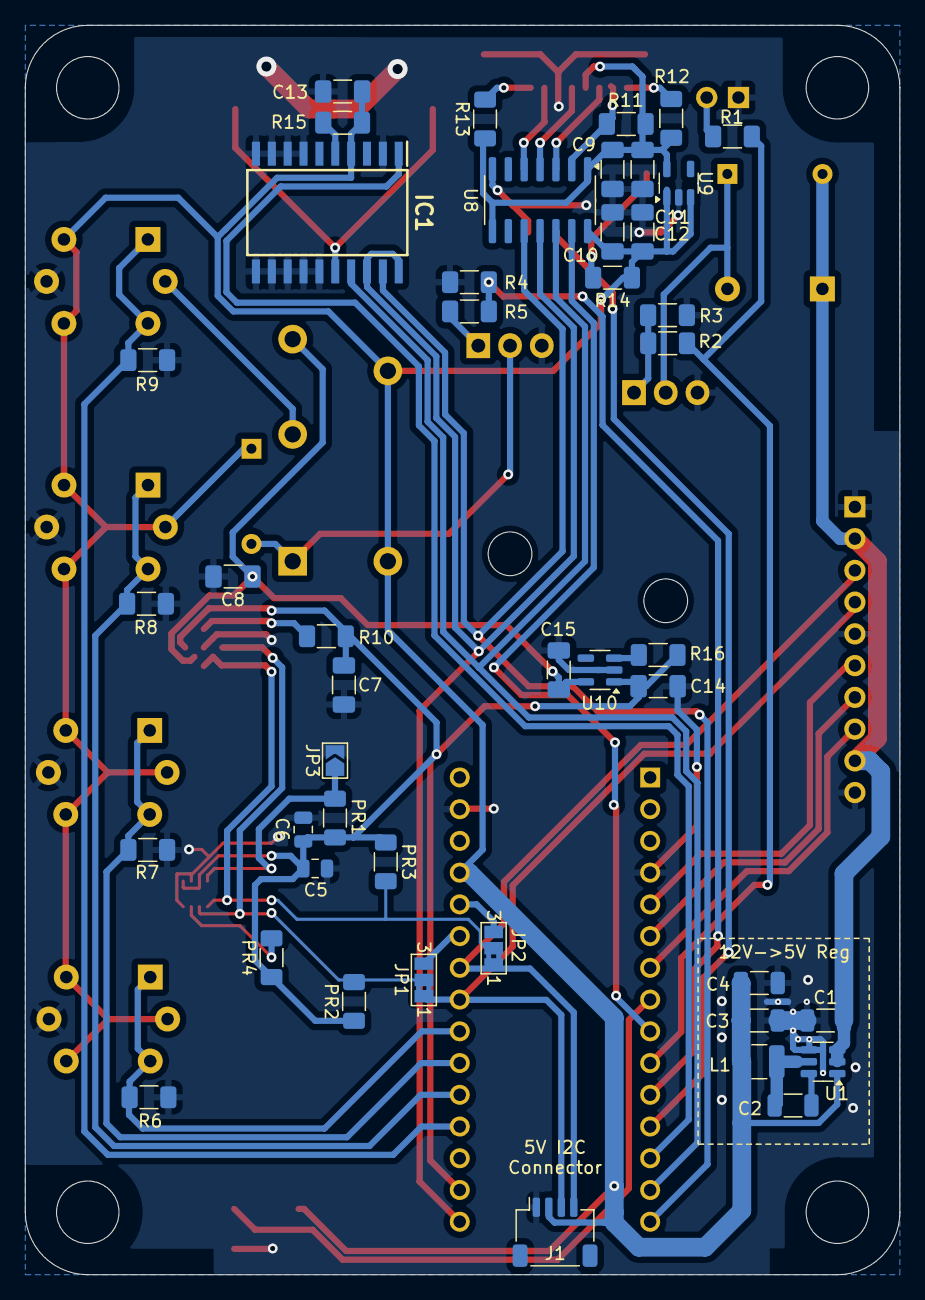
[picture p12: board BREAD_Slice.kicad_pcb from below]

Board: 2 copper layers, 70.0 x 100.0 mm, 69 parts (45 on the bottom side), 49 nets.

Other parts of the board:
BT1: Battery_Cell; BatteryHolder_Keystone_3000_1x12mm
C13: 22p; C_1206_3216Metric_Pad1.33x1.80mm_HandSolder
IC1: DS3234S#; SOIC127P1032X265-20N
Logo1: Logo_Open_Hardware_Small; OSHW-Symbol_6.7x6mm_SilkScreen
R15: 10k; R_1206_3216Metric_Pad1.30x1.75mm_HandSolder

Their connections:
+5V: C13.1, IC1.4 (VCC), R15.2; also elsewhere on the board
/CLK: IC1.18 (SCLK_1), IC1.20 (SCLK_2); also elsewhere on the board
/DI: IC1.17 (DIN); also elsewhere on the board
/DO: IC1.19 (DOUT); also elsewhere on the board
/RTC/VBATT: BT1.1 (+), IC1.16 (VBAT)
/SQW: IC1.5 (~INT/SQW), R15.1
/SS: IC1.1 (~CS); also elsewhere on the board
GND: BT1.2 (-), C13.2, IC1.2 (N.C._1), IC1.7 (N.C._2), IC1.8 (N.C._3), IC1.9 (N.C._4), IC1.10 (N.C._5), IC1.11 (N.C._6), IC1.12 (N.C._7), IC1.13 (N.C._8), IC1.14 (N.C._9), IC1.15 (GND); also elsewhere on the board

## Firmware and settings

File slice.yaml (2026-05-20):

schema_version: "1.0"

# ── Identity ──────────────────────────────────────────────────────────────────
id: "slice-iaqm"
name: "Industrial Air Quality Monitor"
status: "prototype"
category: "sensing"

summary: "Multi-sensor industrial air quality monitor with gas, VOC, temperature, humidity, and pressure sensing."
description: null

# ── Versioning ────────────────────────────────────────────────────────────────
version:
  hardware: "0.1.0"
  firmware: null
  manifest: "0.1.0"

# ── Compatibility ─────────────────────────────────────────────────────────────
compatibility:
  slice_spec: ">=0.1.0 <0.2.0"
  crumbs_protocol: null
  anolis_provider_api: null

# ── Hardware ──────────────────────────────────────────────────────────────────
hardware:
  mcu:
    type: "dev-board-socket"
    form_factor: "nano"
    primary: "ATmega328P"
    supported:
      - "ATmega328P"
  primary_ic:
    manufacturer: "ScioSense"
    part_number: "ENS160"
  hw_gen_current: 1
  hw_gen_supported: [1]
  pcb:
    layers: 2
    thickness: "1.6mm"
    copper_weight: "1oz"
    dimensions: "70mm x 100mm"
  connectors:
    - ref: "J1"
      type: "slice-bus-10pin"
      purpose: "power-and-i2c"
  mounting:
    pattern: "slice-standard-v0"
    hole_size: "M3"
    inset: "5mm"
  pcb_color_prototype: null
  pcb_color_production: null
  enclosure:
    supported: false
    path: null

# ── Electrical ────────────────────────────────────────────────────────────────
electrical:
  input_voltage: "12V"
  logic_voltage: "5V"
  max_current: null
  protection: null
  isolation: null

# ── Interfaces ────────────────────────────────────────────────────────────────
interfaces:
  host:
    type: "i2c"
    address_default: null
    address_configurable: false
  data:
    inputs:
      - name: "BME280"
        type: "i2c-sensor"
      - name: "ENS160"
        type: "i2c-sensor"
      - name: "MQ-7"
        type: "analog-gas"
      - name: "MQ-137"
        type: "analog-gas"
      - name: "MQ-8"
        type: "analog-gas"
      - name: "MQ-136"
        type: "analog-gas"
      - name: "MQ-2"
        type: "analog-gas"
      - name: "MQ-4"
        type: "analog-gas"
    outputs:
      - name: "BUZZER"
        type: "digital-alarm"
      - name: "LED"
        type: "digital-alarm"

# ── Capabilities ──────────────────────────────────────────────────────────────
capabilities:
  - id: "gas_sensing"
    channels: 6
    control_modes: []
  - id: "environmental_sensing"
    channels: 1
    control_modes: []
  - id: "voc_sensing"
    channels: 1
    control_modes: []
  - id: "data_logging"
    channels: 1
    control_modes: []

# ── Firmware ──────────────────────────────────────────────────────────────────
firmware: null

# ── Protocol ──────────────────────────────────────────────────────────────────
protocol: null

# ── Software ──────────────────────────────────────────────────────────────────
software: null

# ── Artifacts ─────────────────────────────────────────────────────────────────
artifacts:
  schematic: "hardware/BREAD_Slice.kicad_sch"
  pcb: "hardware/BREAD_Slice.kicad_pcb"
  firmware: null
  docs: null
  bom: "hardware/iaqm_slice_BOM.ods"
  gerbers: "hardware/Gerbers.zip"
  pick_and_place: null
  datasheets: []

# ── Manufacturing ─────────────────────────────────────────────────────────────
manufacturing: null

# ── Validation ────────────────────────────────────────────────────────────────
validation: null

# ── Safety ────────────────────────────────────────────────────────────────────
safety:
  hazards:
    - "MQ sensors contain heated coils — fire risk if improperly powered"
  max_safe_voltage: "12V"
  intended_environment: "industrial"
  not_for:
    - "human safety critical systems"
    - "certified gas detection"

# ── Dependencies ──────────────────────────────────────────────────────────────
dependencies: null

# ── Relations ─────────────────────────────────────────────────────────────────
related: null

# ── Maintainers ───────────────────────────────────────────────────────────────
maintainers:
  - name: "Cameron Brooks"
    role: "owner"

# ── License ───────────────────────────────────────────────────────────────────
license:
  hardware: "CERN-OHL-S-2.0"
  firmware: null
  software: null
  docs: "CC-BY-4.0"

# ── Repository ────────────────────────────────────────────────────────────────
repository:
  url: "https://github.com/feastorg/Slice_IAQM"

# ── Metadata ──────────────────────────────────────────────────────────────────
metadata:
  created: "2026-05-19"
  updated: "2026-05-19"
  tags:
    - "air-quality"
    - "gas-sensor"
    - "environmental"
    - "industrial-monitoring"
    - "data-logging"

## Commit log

2024-08-30 completed requirements and conceptual design, added gas sensors part of schematic for detailed design
    [BREAD_Slice.kicad_sch, mq_gas_sensor.kicad_sch]
2024-09-06 completed schematic
    [1V8_reg.kicad_sch, BREAD_Slice.kicad_sch, bme280.kicad_sch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]
2024-09-08 organized schem and updated readme
    [1V8_reg.kicad_sch, BREAD_Slice.kicad_sch, bme280.kicad_sch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]
2024-09-09 completed board
    [1V8_reg.kicad_sch, BREAD_Slice.kicad_pcb, BREAD_Slice.kicad_sch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]
2024-09-19 added product links to bom
    [BOM_TEMP.ods, iaqm_slice.csv]
2024-09-19 updated parts list and swapped relay to omron var
    [BREAD_Slice.kicad_pcb, BREAD_Slice.kicad_sch, mq_gas_sensor.kicad_sch]
2024-09-24 checked output for order
    [BREAD_Slice.kicad_pcb, BREAD_Slice.kicad_sch, mq_gas_sensor.kicad_sch]
2024-09-24 local push
    [BREAD_Slice-B_Cu.gbr, BREAD_Slice-B_Mask.gbr, BREAD_Slice-B_Paste.gbr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]
2024-09-30 JLCPCB order rev-A
    [BREAD_Slice-B_Cu.gbr, BREAD_Slice-B_Mask.gbr, BREAD_Slice-B_Paste.gbr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]
2024-10-25 final touches for order and assembly
    [1V8_reg.kicad_sch, BREAD_Slice.kicad_sch, ens160.kicad_sch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]
2026-05-24 📄 KiBot index + board renders (auto)
